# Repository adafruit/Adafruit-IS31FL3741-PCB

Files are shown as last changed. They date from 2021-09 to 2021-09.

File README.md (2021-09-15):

## Adafruit IS31FL3741 13x9 PWM RGB LED Matrix Driver PCB

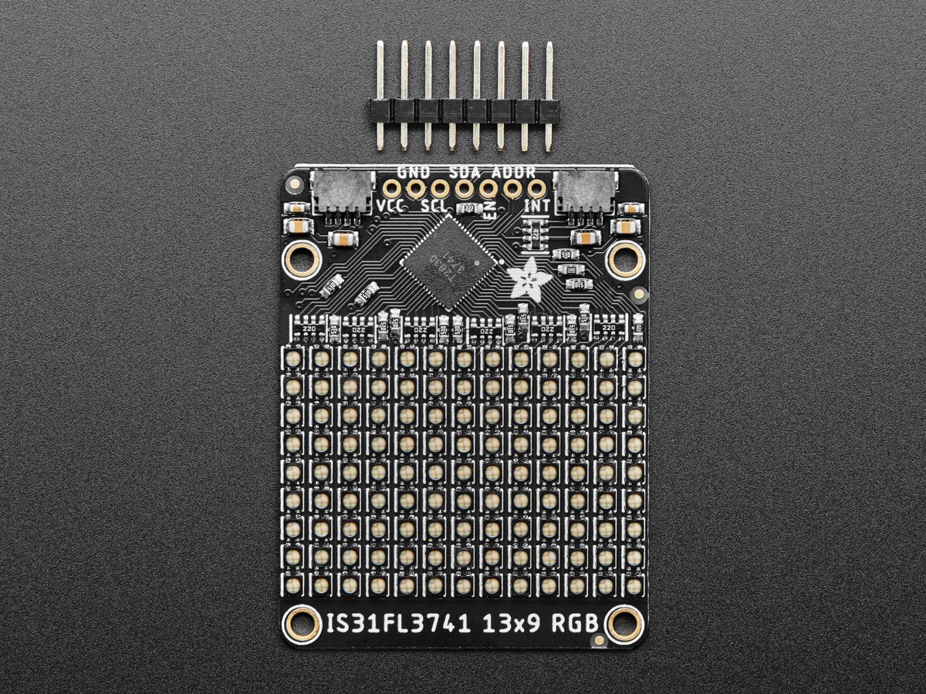
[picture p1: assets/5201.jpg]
<a href="http://www.adafruit.com/products/5201"><br/>
Click here to purchase one from the Adafruit shop</a>

PCB files for the Adafruit IS31FL3741 13x9 PWM RGB LED Matrix Driver. 

Format is EagleCAD schematic and board layout
* https://www.adafruit.com/product/5201

### Description

Add a splash of RGB LEDs to a project you're working on, with this adorable 13x9 RGB LED matrix breakout. It features -- no surprise -- 117 RGB LEDs, each one 2x2mm in size, in a 13x9 grid with 3mm pitch spacing.

Unlike our 8x8 dotstar grid here, these are not NeoPixel or DotStar or other 'smart' RGB LEDs. Instead of having a lil chip in each LED, there's one large controller chip that handles all the PWM for you. The ISSI IS32FL3741 communicates over I2C and can set each LED element with 8 bit PWM for 24-bit color across the RGB elements, for beautiful color! There's an adjustable current driver so you can brighten or dim the whole display without losing color resolution.

Each assembled board comes with the grid, four mounting holes, and the IS31FL3741 chip with all supporting circuitry. The board can run from 3.3 to 5V DC power and logic - powering from 5V is recommended since the green and blue LEDs look better with the extra headroom. We designed the PCB so you can tile the boards side-to-side if you desire, you'll just have to cut/solder the jumpers on the bottom to change the I2C address: Up to 4 boards can share one I2C bus.

Use Arduino or CircuitPython/Python to quickly set pixels to any color you desire. Note that I2C makes this board very easy to wire up compared to our "HUB75"-style RGB LED Matrices but that also makes the display slower because each pixel must be written over I2C. For a small display with simple animations, its fine - but if you want to do video or larger graphics we recommend upgrading to the HUB75 style.

We made it easy for you to get some color right into your next project. The LED matrix and circuitry is soldered onto a custom-made PCB with two STEMMA QT connectors on the top, and are compatible with the SparkFun Qwiic I2C connectors. This allows you to make solderless connections between your development board and the IS31FL3741 or to chain it with a wide range of other sensors and accessories using a compatible cable.

### License

Adafruit invests time and resources providing this open source design, please support Adafruit and open-source hardware by purchasing products from [Adafruit](https://www.adafruit.com)!

Designed by Limor Fried/Ladyada for Adafruit Industries.

Creative Commons Attribution/Share-Alike, all text above must be included in any redistribution. 
See license.txt for additional details.

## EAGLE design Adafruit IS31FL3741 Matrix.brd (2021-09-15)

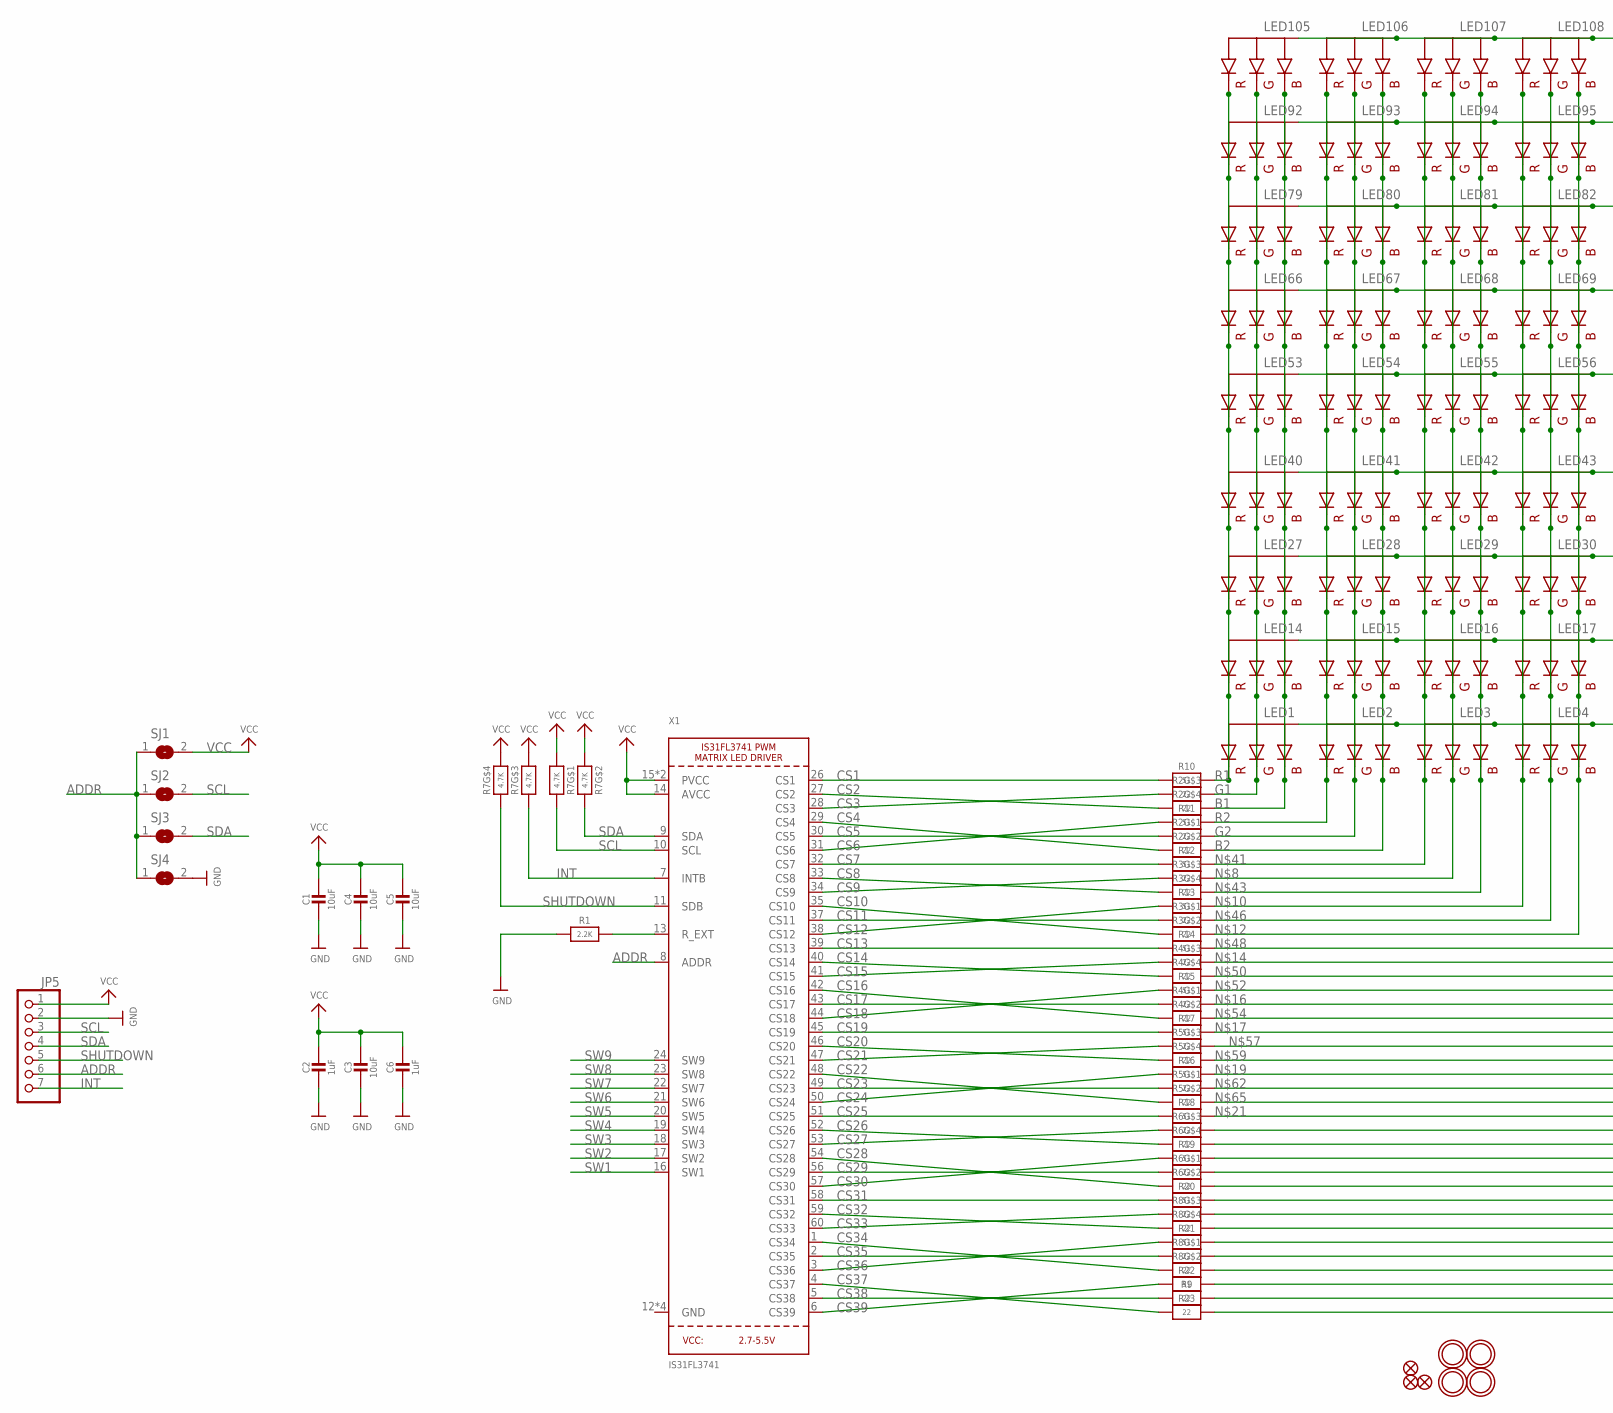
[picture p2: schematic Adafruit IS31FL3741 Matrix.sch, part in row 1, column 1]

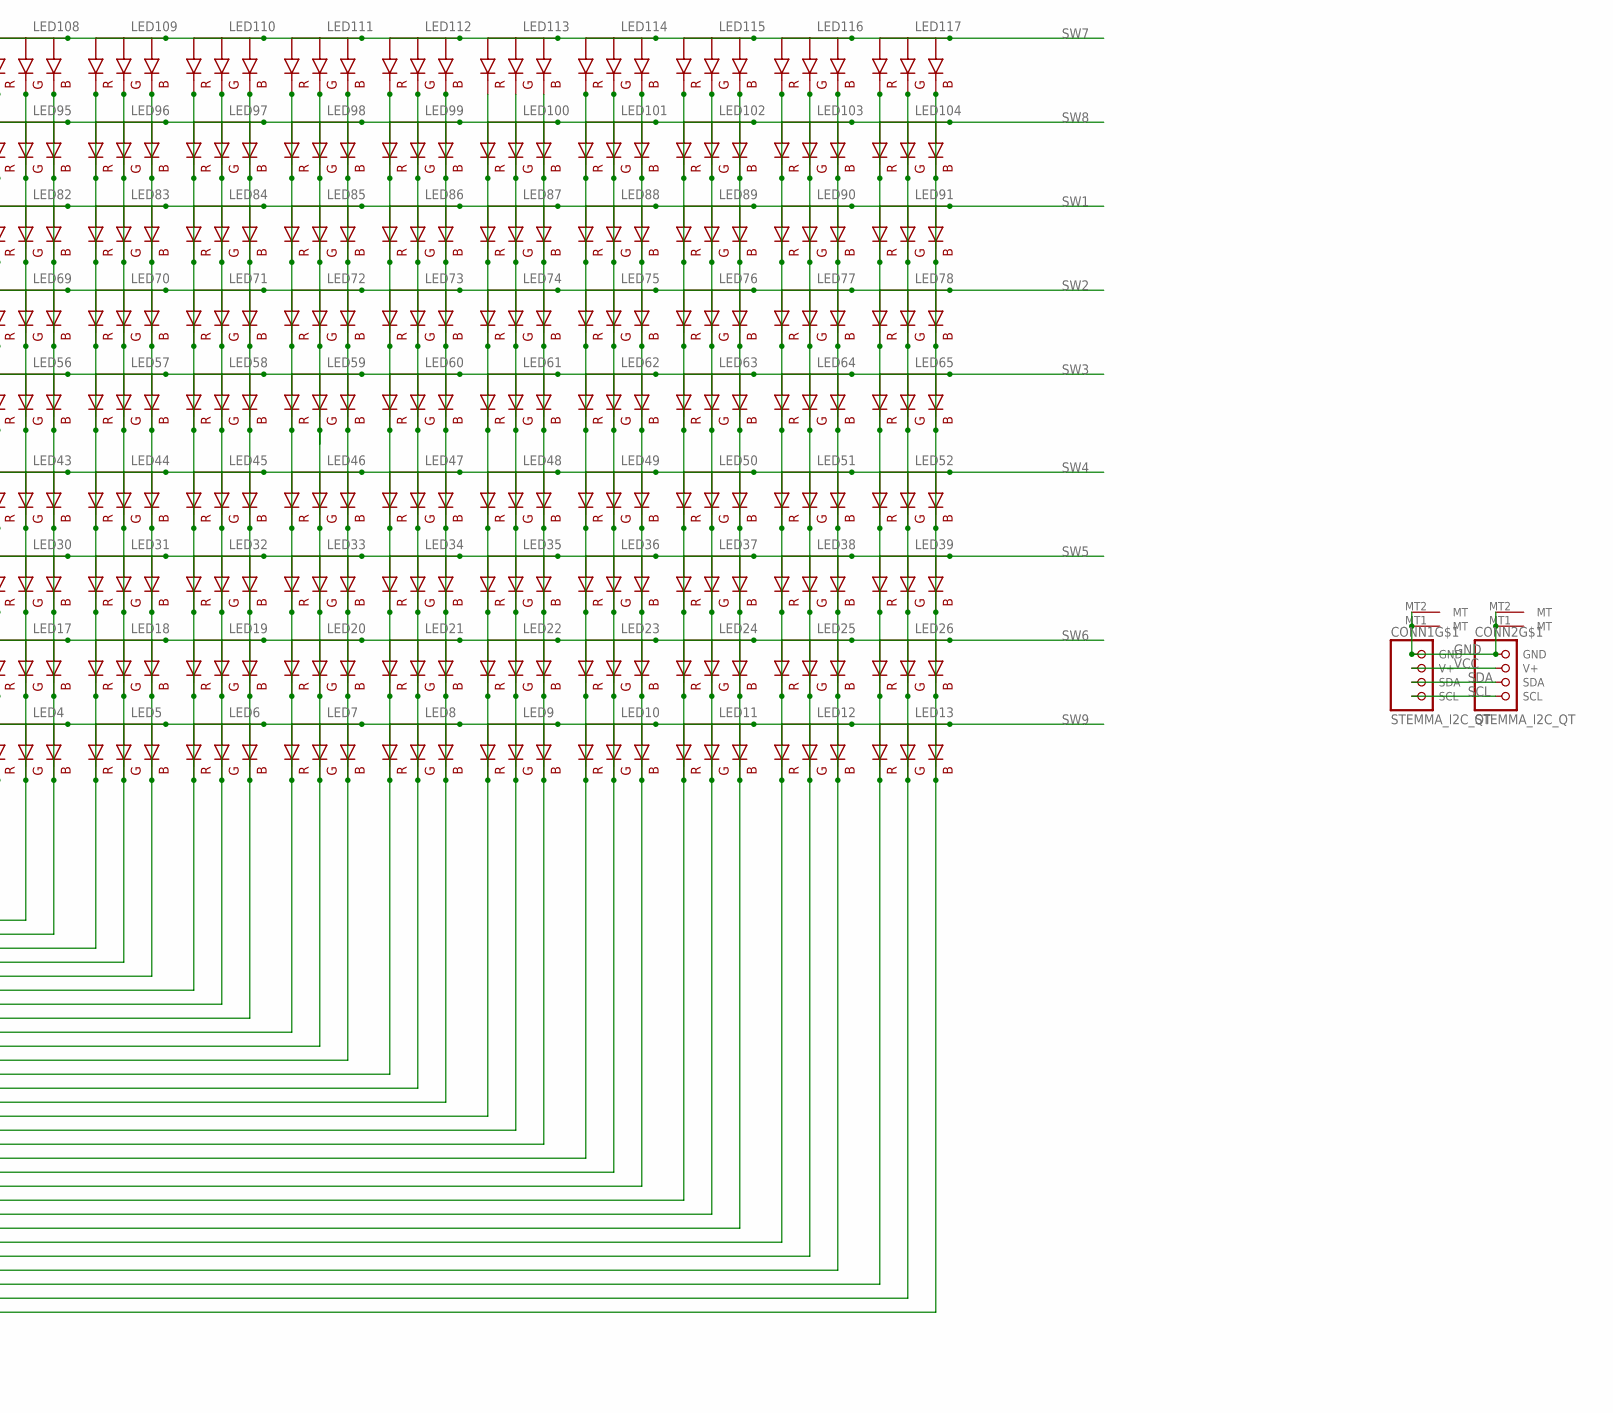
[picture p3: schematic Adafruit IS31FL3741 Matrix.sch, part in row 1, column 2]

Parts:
C1, C3, C4, C5: 10uF; 0805-NO
C2, C6: 1uF; 0603-NO
CONN1, CONN2: STEMMA_I2C_QT; JST_SH4
FID1, FID2, FID3: FIDUCIAL_1MM
JP5: HEADER-1X7THICKER; 1X07_ROUND_76
LED1, LED2, LED3, LED4, LED5, LED6, LED7, LED8, LED9, LED10, LED11, LED12, LED13, LED14, LED15, LED16, LED17, LED18, LED19, LED20, LED21, LED22, LED23, LED24, LED25, LED26, LED27, LED28, LED29, LED30, LED31, LED32, LED33, LED34, LED35, LED36, LED37, LED38, LED39, LED40, LED41, LED42, LED43, LED44, LED45, LED46, LED47, LED48, LED49, LED50, LED51, LED52, LED53, LED54, LED55, LED56, LED57, LED58, LED59, LED60, LED61, LED62, LED63, LED64, LED65, LED66, LED67, LED68, LED69, LED70, LED71, LED72, LED73, LED74, LED75, LED76, LED77, LED78, LED79, LED80, LED81, LED82, LED83, LED84, LED85, LED86, LED87, LED88, LED89, LED90, LED91, LED92, LED93, LED94, LED95, LED96, LED97, LED98, LED99, LED100, LED101, LED102, LED103, LED104, LED105, LED106, LED107, LED108, LED109, LED110, LED111, LED112, LED113, LED114, LED115, LED116, LED117: RGBLED_CA_2121; RGBLED_2121
R1: 2.2K; 0603-NO
R2, R3, R4, R5, R6, R8: 22; RESPACK_4X0603
R7: 4.7K; RESPACK_4X0603
R9, R23: 22; 0603-NO
R10, R11, R12, R13, R14, R15, R16, R17, R18, R19, R20, R21, R22: 51; 0603-NO
SJ1, SJ2, SJ3: SOLDERJUMPER; SOLDERJUMPER_ARROW_NOPASTE
SJ4: SOLDERJUMPERCLOSED; SOLDERJUMPER_CLOSEDWIRE
U$3, U$4, U$5, U$6: MOUNTINGHOLE2.5; MOUNTINGHOLE_2.5_PLATED
X1: IS31FL3741; QFN60_7MM

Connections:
ADDR: JP5.6, SJ1.1, SJ2.1, SJ3.1, SJ4.1, X1.8 (ADDR)
B1: LED1.B (BLUE), LED14.B (BLUE), LED27.B (BLUE), LED40.B (BLUE), LED53.B (BLUE), LED66.B (BLUE), LED79.B (BLUE), LED92.B (BLUE), LED105.B (BLUE), R2.5 (2)
B2: LED2.B (BLUE), LED15.B (BLUE), LED28.B (BLUE), LED41.B (BLUE), LED54.B (BLUE), LED67.B (BLUE), LED80.B (BLUE), LED93.B (BLUE), LED106.B (BLUE), R2.7 (2)
CS1: R10.1, X1.26 (CS1)
CS2: R2.4 (1), X1.27 (CS2)
CS3: R2.3 (1), X1.28 (CS3)
CS4: R2.2 (1), X1.29 (CS4)
CS5: R2.1, X1.30 (CS5)
CS6: R11.1, X1.31 (CS6)
CS7: R12.1, X1.32 (CS7)
CS8: R3.4 (1), X1.33 (CS8)
CS9: R3.3 (1), X1.34 (CS9)
CS10: R3.2 (1), X1.35 (CS10)
CS11: R3.1, X1.37 (CS11)
CS12: R13.1, X1.38 (CS12)
CS13: R14.1, X1.39 (CS13)
CS14: R4.4 (1), X1.40 (CS14)
CS15: R4.3 (1), X1.41 (CS15)
CS16: R4.2 (1), X1.42 (CS16)
CS17: R4.1, X1.43 (CS17)
CS18: R15.1, X1.44 (CS18)
CS19: R17.1, X1.45 (CS19)
CS20: R5.4 (1), X1.46 (CS20)
CS21: R5.3 (1), X1.47 (CS21)
CS22: R5.2 (1), X1.48 (CS22)
CS23: R5.1, X1.49 (CS23)
CS24: R16.1, X1.50 (CS24)
CS25: R18.1, X1.51 (CS25)
CS26: R6.4 (1), X1.52 (CS26)
CS27: R6.3 (1), X1.53 (CS27)
CS28: R6.2 (1), X1.54 (CS28)
CS29: R6.1, X1.56 (CS29)
CS30: R19.1, X1.57 (CS30)
CS31: R20.1, X1.58 (CS31)
CS32: R8.4 (1), X1.59 (CS32)
CS33: R8.3 (1), X1.60 (CS33)
CS34: R8.2 (1), X1.1 (CS34)
CS35: R8.1, X1.2 (CS35)
CS36: R21.1, X1.3 (CS36)
CS37: R23.1, X1.4 (CS37)
CS38: R9.1, X1.5 (CS38)
CS39: R22.1, X1.6 (CS39)
G1: LED1.G (GREEN), LED14.G (GREEN), LED27.G (GREEN), LED40.G (GREEN), LED53.G (GREEN), LED66.G (GREEN), LED79.G (GREEN), LED92.G (GREEN), LED105.G (GREEN), R2.6 (2)
G2: LED2.G (GREEN), LED15.G (GREEN), LED28.G (GREEN), LED41.G (GREEN), LED54.G (GREEN), LED67.G (GREEN), LED80.G (GREEN), LED93.G (GREEN), LED106.G (GREEN), R2.8 (2)
GND: C1.2, C2.2, C3.2, C4.2, C5.2, C6.2, CONN1.1 (GND), CONN1.MT1 (MT), CONN1.MT2 (MT), CONN2.1 (GND), CONN2.MT1 (MT), CONN2.MT2 (MT), JP5.2, R1.1, SJ4.2, X1.12 (GND), X1.36 (GND), X1.55 (GND), X1.THERMAL (GND)
INT: JP5.7, R7.3 (1), X1.7 (INTB)
unnamed: R1.2, X1.13 (R_EXT)
unnamed: LED3.G (GREEN), LED16.G (GREEN), LED29.G (GREEN), LED42.G (GREEN), LED55.G (GREEN), LED68.G (GREEN), LED81.G (GREEN), LED94.G (GREEN), LED107.G (GREEN), R3.6 (2)
unnamed: LED4.R (RED), LED17.R (RED), LED30.R (RED), LED43.R (RED), LED56.R (RED), LED69.R (RED), LED82.R (RED), LED95.R (RED), LED108.R (RED), R13.2
unnamed: LED4.B (BLUE), LED17.B (BLUE), LED30.B (BLUE), LED43.B (BLUE), LED56.B (BLUE), LED69.B (BLUE), LED82.B (BLUE), LED95.B (BLUE), LED108.B (BLUE), R3.7 (2)
unnamed: LED5.G (GREEN), LED18.G (GREEN), LED31.G (GREEN), LED44.G (GREEN), LED57.G (GREEN), LED70.G (GREEN), LED83.G (GREEN), LED96.G (GREEN), LED109.G (GREEN), R4.6 (2)
unnamed: LED6.G (GREEN), LED19.G (GREEN), LED32.G (GREEN), LED45.G (GREEN), LED58.G (GREEN), LED71.G (GREEN), LED84.G (GREEN), LED97.G (GREEN), LED110.G (GREEN), R4.8 (2)
unnamed: LED7.R (RED), LED20.R (RED), LED33.R (RED), LED46.R (RED), LED59.R (RED), LED72.R (RED), LED85.R (RED), LED98.R (RED), LED111.R (RED), R17.2
unnamed: LED8.R (RED), LED21.R (RED), LED34.R (RED), LED47.R (RED), LED60.R (RED), LED73.R (RED), LED86.R (RED), LED99.R (RED), LED112.R (RED), R16.2
unnamed: LED9.R (RED), LED22.R (RED), LED35.R (RED), LED48.R (RED), LED61.R (RED), LED74.R (RED), LED87.R (RED), LED100.R (RED), LED113.R (RED), R18.2
unnamed: LED9.B (BLUE), LED22.B (BLUE), LED35.B (BLUE), LED48.B (BLUE), LED61.B (BLUE), LED74.B (BLUE), LED87.B (BLUE), LED100.B (BLUE), LED113.B (BLUE), R6.5 (2)
unnamed: LED10.G (GREEN), LED23.G (GREEN), LED36.G (GREEN), LED49.G (GREEN), LED62.G (GREEN), LED75.G (GREEN), LED88.G (GREEN), LED101.G (GREEN), LED114.G (GREEN), R6.8 (2)
unnamed: LED11.R (RED), LED24.R (RED), LED37.R (RED), LED50.R (RED), LED63.R (RED), LED76.R (RED), LED89.R (RED), LED102.R (RED), LED115.R (RED), R20.2
unnamed: LED11.B (BLUE), LED24.B (BLUE), LED37.B (BLUE), LED50.B (BLUE), LED63.B (BLUE), LED76.B (BLUE), LED89.B (BLUE), LED102.B (BLUE), LED115.B (BLUE), R8.5 (2)
unnamed: LED12.G (GREEN), LED25.G (GREEN), LED38.G (GREEN), LED51.G (GREEN), LED64.G (GREEN), LED77.G (GREEN), LED90.G (GREEN), LED103.G (GREEN), LED116.G (GREEN), R8.8 (2)
unnamed: LED13.R (RED), LED26.R (RED), LED39.R (RED), LED52.R (RED), LED65.R (RED), LED78.R (RED), LED91.R (RED), LED104.R (RED), LED117.R (RED), R22.2
unnamed: LED13.B (BLUE), LED26.B (BLUE), LED39.B (BLUE), LED52.B (BLUE), LED65.B (BLUE), LED78.B (BLUE), LED91.B (BLUE), LED104.B (BLUE), LED117.B (BLUE), R23.2
unnamed: LED3.R (RED), LED16.R (RED), LED29.R (RED), LED42.R (RED), LED55.R (RED), LED68.R (RED), LED81.R (RED), LED94.R (RED), LED107.R (RED), R12.2
unnamed: LED3.B (BLUE), LED16.B (BLUE), LED29.B (BLUE), LED42.B (BLUE), LED55.B (BLUE), LED68.B (BLUE), LED81.B (BLUE), LED94.B (BLUE), LED107.B (BLUE), R3.5 (2)
unnamed: LED4.G (GREEN), LED17.G (GREEN), LED30.G (GREEN), LED43.G (GREEN), LED56.G (GREEN), LED69.G (GREEN), LED82.G (GREEN), LED95.G (GREEN), LED108.G (GREEN), R3.8 (2)
unnamed: LED5.R (RED), LED18.R (RED), LED31.R (RED), LED44.R (RED), LED57.R (RED), LED70.R (RED), LED83.R (RED), LED96.R (RED), LED109.R (RED), R14.2
unnamed: LED5.B (BLUE), LED18.B (BLUE), LED31.B (BLUE), LED44.B (BLUE), LED57.B (BLUE), LED70.B (BLUE), LED83.B (BLUE), LED96.B (BLUE), LED109.B (BLUE), R4.5 (2)
unnamed: LED6.R (RED), LED19.R (RED), LED32.R (RED), LED45.R (RED), LED58.R (RED), LED71.R (RED), LED84.R (RED), LED97.R (RED), LED110.R (RED), R15.2
unnamed: LED6.B (BLUE), LED19.B (BLUE), LED32.B (BLUE), LED45.B (BLUE), LED58.B (BLUE), LED71.B (BLUE), LED84.B (BLUE), LED97.B (BLUE), LED110.B (BLUE), R4.7 (2)
unnamed: LED7.G (GREEN), LED20.G (GREEN), LED33.G (GREEN), LED46.G (GREEN), LED59.G (GREEN), LED72.G (GREEN), LED85.G (GREEN), LED98.G (GREEN), LED111.G (GREEN), R5.6 (2)
unnamed: LED7.B (BLUE), LED20.B (BLUE), LED33.B (BLUE), LED46.B (BLUE), LED59.B (BLUE), LED72.B (BLUE), LED85.B (BLUE), LED98.B (BLUE), LED111.B (BLUE), R5.5 (2)
unnamed: LED8.G (GREEN), LED21.G (GREEN), LED34.G (GREEN), LED47.G (GREEN), LED60.G (GREEN), LED73.G (GREEN), LED86.G (GREEN), LED99.G (GREEN), LED112.G (GREEN), R5.8 (2)
unnamed: LED8.B (BLUE), LED21.B (BLUE), LED34.B (BLUE), LED47.B (BLUE), LED60.B (BLUE), LED73.B (BLUE), LED86.B (BLUE), LED99.B (BLUE), LED112.B (BLUE), R5.7 (2)
unnamed: LED9.G (GREEN), LED22.G (GREEN), LED35.G (GREEN), LED48.G (GREEN), LED61.G (GREEN), LED74.G (GREEN), LED87.G (GREEN), LED100.G (GREEN), LED113.G (GREEN), R6.6 (2)
unnamed: LED10.R (RED), LED23.R (RED), LED36.R (RED), LED49.R (RED), LED62.R (RED), LED75.R (RED), LED88.R (RED), LED101.R (RED), LED114.R (RED), R19.2
unnamed: LED10.B (BLUE), LED23.B (BLUE), LED36.B (BLUE), LED49.B (BLUE), LED62.B (BLUE), LED75.B (BLUE), LED88.B (BLUE), LED101.B (BLUE), LED114.B (BLUE), R6.7 (2)
unnamed: LED11.G (GREEN), LED24.G (GREEN), LED37.G (GREEN), LED50.G (GREEN), LED63.G (GREEN), LED76.G (GREEN), LED89.G (GREEN), LED102.G (GREEN), LED115.G (GREEN), R8.6 (2)
unnamed: LED12.R (RED), LED25.R (RED), LED38.R (RED), LED51.R (RED), LED64.R (RED), LED77.R (RED), LED90.R (RED), LED103.R (RED), LED116.R (RED), R21.2
unnamed: LED12.B (BLUE), LED25.B (BLUE), LED38.B (BLUE), LED51.B (BLUE), LED64.B (BLUE), LED77.B (BLUE), LED90.B (BLUE), LED103.B (BLUE), LED116.B (BLUE), R8.7 (2)
unnamed: LED13.G (GREEN), LED26.G (GREEN), LED39.G (GREEN), LED52.G (GREEN), LED65.G (GREEN), LED78.G (GREEN), LED91.G (GREEN), LED104.G (GREEN), LED117.G (GREEN), R9.2
R1: LED1.R (RED), LED14.R (RED), LED27.R (RED), LED40.R (RED), LED53.R (RED), LED66.R (RED), LED79.R (RED), LED92.R (RED), LED105.R (RED), R10.2
R2: LED2.R (RED), LED15.R (RED), LED28.R (RED), LED41.R (RED), LED54.R (RED), LED67.R (RED), LED80.R (RED), LED93.R (RED), LED106.R (RED), R11.2
SCL: CONN1.4 (SCL), CONN2.4 (SCL), JP5.3, R7.8 (2), SJ2.2, X1.10 (SCL)
SDA: CONN1.3 (SDA), CONN2.3 (SDA), JP5.4, R7.7 (2), SJ3.2, X1.9 (SDA)
SHUTDOWN: JP5.5, R7.4 (1), X1.11 (SDB)
SW1: LED79.A (VCC), LED80.A (VCC), LED81.A (VCC), LED82.A (VCC), LED83.A (VCC), LED84.A (VCC), LED85.A (VCC), LED86.A (VCC), LED87.A (VCC), LED88.A (VCC), LED89.A (VCC), LED90.A (VCC), LED91.A (VCC), X1.16 (SW1)
SW2: LED66.A (VCC), LED67.A (VCC), LED68.A (VCC), LED69.A (VCC), LED70.A (VCC), LED71.A (VCC), LED72.A (VCC), LED73.A (VCC), LED74.A (VCC), LED75.A (VCC), LED76.A (VCC), LED77.A (VCC), LED78.A (VCC), X1.17 (SW2)
SW3: LED53.A (VCC), LED54.A (VCC), LED55.A (VCC), LED56.A (VCC), LED57.A (VCC), LED58.A (VCC), LED59.A (VCC), LED60.A (VCC), LED61.A (VCC), LED62.A (VCC), LED63.A (VCC), LED64.A (VCC), LED65.A (VCC), X1.18 (SW3)
SW4: LED40.A (VCC), LED41.A (VCC), LED42.A (VCC), LED43.A (VCC), LED44.A (VCC), LED45.A (VCC), LED46.A (VCC), LED47.A (VCC), LED48.A (VCC), LED49.A (VCC), LED50.A (VCC), LED51.A (VCC), LED52.A (VCC), X1.19 (SW4)
SW5: LED27.A (VCC), LED28.A (VCC), LED29.A (VCC), LED30.A (VCC), LED31.A (VCC), LED32.A (VCC), LED33.A (VCC), LED34.A (VCC), LED35.A (VCC), LED36.A (VCC), LED37.A (VCC), LED38.A (VCC), LED39.A (VCC), X1.20 (SW5)
SW6: LED14.A (VCC), LED15.A (VCC), LED16.A (VCC), LED17.A (VCC), LED18.A (VCC), LED19.A (VCC), LED20.A (VCC), LED21.A (VCC), LED22.A (VCC), LED23.A (VCC), LED24.A (VCC), LED25.A (VCC), LED26.A (VCC), X1.21 (SW6)
SW7: LED105.A (VCC), LED106.A (VCC), LED107.A (VCC), LED108.A (VCC), LED109.A (VCC), LED110.A (VCC), LED111.A (VCC), LED112.A (VCC), LED113.A (VCC), LED114.A (VCC), LED115.A (VCC), LED116.A (VCC), LED117.A (VCC), X1.22 (SW7)
SW8: LED92.A (VCC), LED93.A (VCC), LED94.A (VCC), LED95.A (VCC), LED96.A (VCC), LED97.A (VCC), LED98.A (VCC), LED99.A (VCC), LED100.A (VCC), LED101.A (VCC), LED102.A (VCC), LED103.A (VCC), LED104.A (VCC), X1.23 (SW8)
SW9: LED1.A (VCC), LED2.A (VCC), LED3.A (VCC), LED4.A (VCC), LED5.A (VCC), LED6.A (VCC), LED7.A (VCC), LED8.A (VCC), LED9.A (VCC), LED10.A (VCC), LED11.A (VCC), LED12.A (VCC), LED13.A (VCC), X1.24 (SW9)
VCC: C1.1, C2.1, C3.1, C4.1, C5.1, C6.1, CONN1.2 (V+), CONN2.2 (V+), JP5.1, R7.1, R7.2 (1), R7.5 (2), R7.6 (2), SJ1.2, X1.14 (AVCC), X1.15 (PVCC), X1.25 (PVCC)

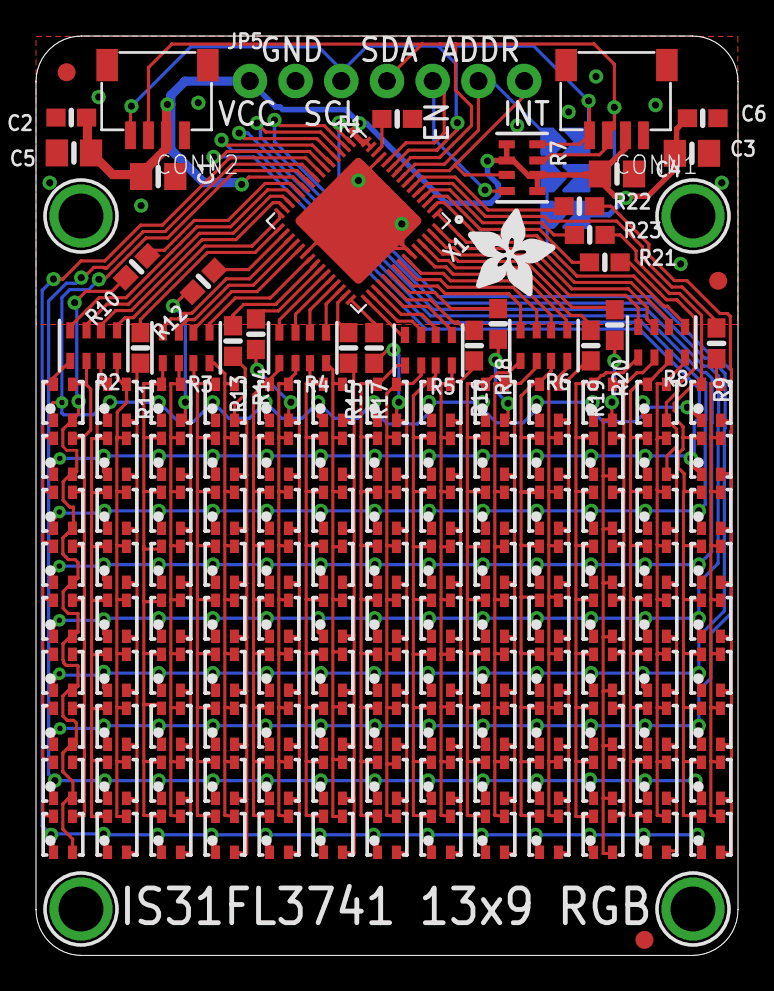
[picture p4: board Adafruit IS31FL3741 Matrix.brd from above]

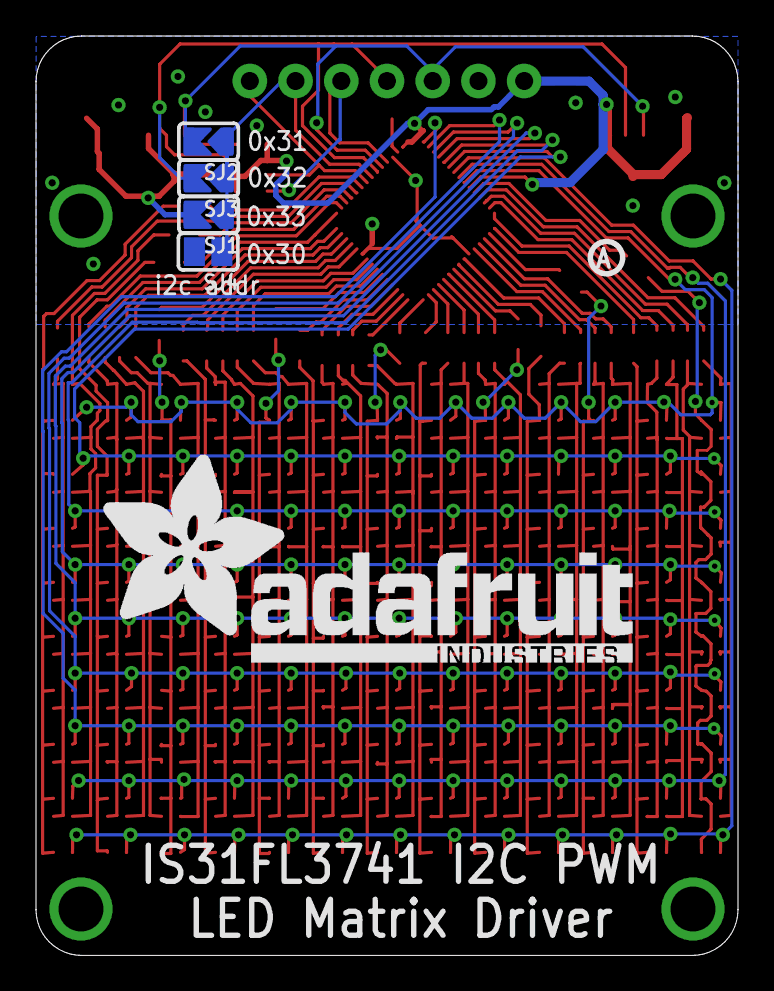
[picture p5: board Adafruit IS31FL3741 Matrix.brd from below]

Board: 2 copper layers, 39.0 x 51.1 mm, 164 parts (6 on the bottom side), 95 nets.

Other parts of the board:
U$10: ADAFRUIT_5MM
U$11: PCBFEAT-REV-040
U$16: ADAFRUIT_TEXT_30MM

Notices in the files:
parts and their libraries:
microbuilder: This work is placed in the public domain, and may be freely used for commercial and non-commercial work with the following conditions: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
